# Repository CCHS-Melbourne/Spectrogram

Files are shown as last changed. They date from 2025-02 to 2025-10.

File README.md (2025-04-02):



# Spectrogram

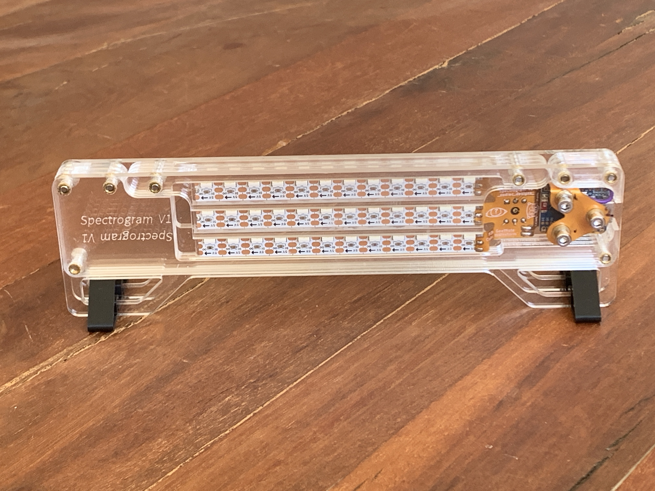
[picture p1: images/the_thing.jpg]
the_thing


It's a 36 LED stack of neopixels joy with an integrated microphone, running MicroPython:

* Audio reactive LEDs
* Acrylic-ready, to show off your creative animations
* Stepped structure to elimate gaps between edge-lit panels
* Touch-enabled to switch between all its range of features

### Building

To build the firmware it helps to use `mpbuild` like so, since this hardware will not work without `ulab`:

```
$ git clone https://github.com/mattytrentini/mpbuild && cd mpbuild
$ git clone https://github.com/v923z/micropython-ulab ulab
$ python3 -mvenv .venv && source .venv/bin/activate && pip install -e .
(.venv)$ mpbuild build ESP32_GENERIC_S3 FLASH_4M USER_C_MODULES=$PWD/ulab/code/micropython.cmake all
```

The resulting object you want to flash with the `esptool.py` command from the previous section is typically named `firmware.bin`.

### Running

```sh
cd software/micropython
./run.sh
```

### Closeup

Uoooohhh

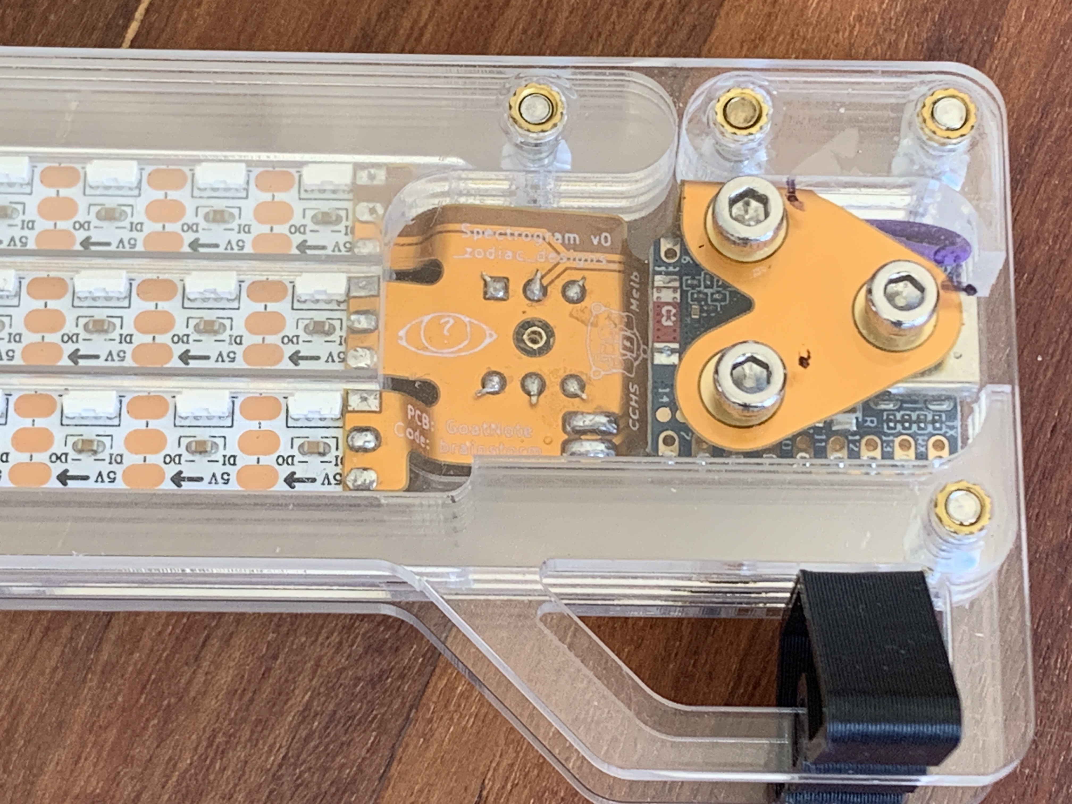
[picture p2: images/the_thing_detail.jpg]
the_thing_detail


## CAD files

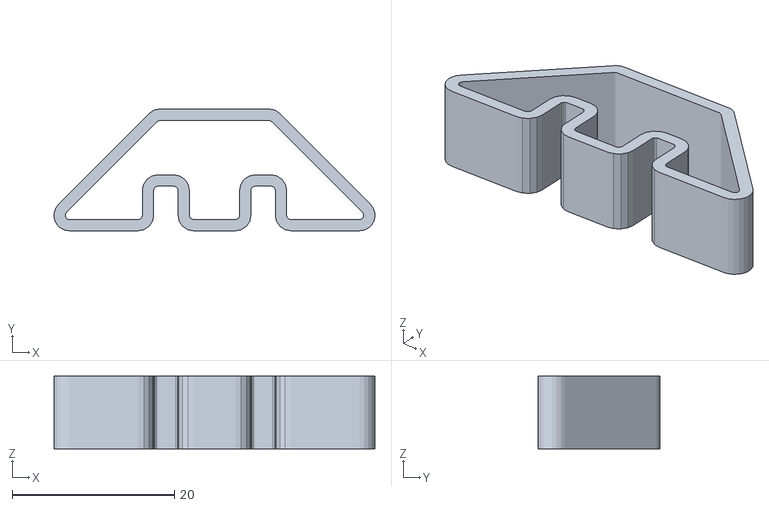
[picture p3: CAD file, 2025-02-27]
hardware/3d_print/foot.stl
39.6 x 15.0 x 9.00

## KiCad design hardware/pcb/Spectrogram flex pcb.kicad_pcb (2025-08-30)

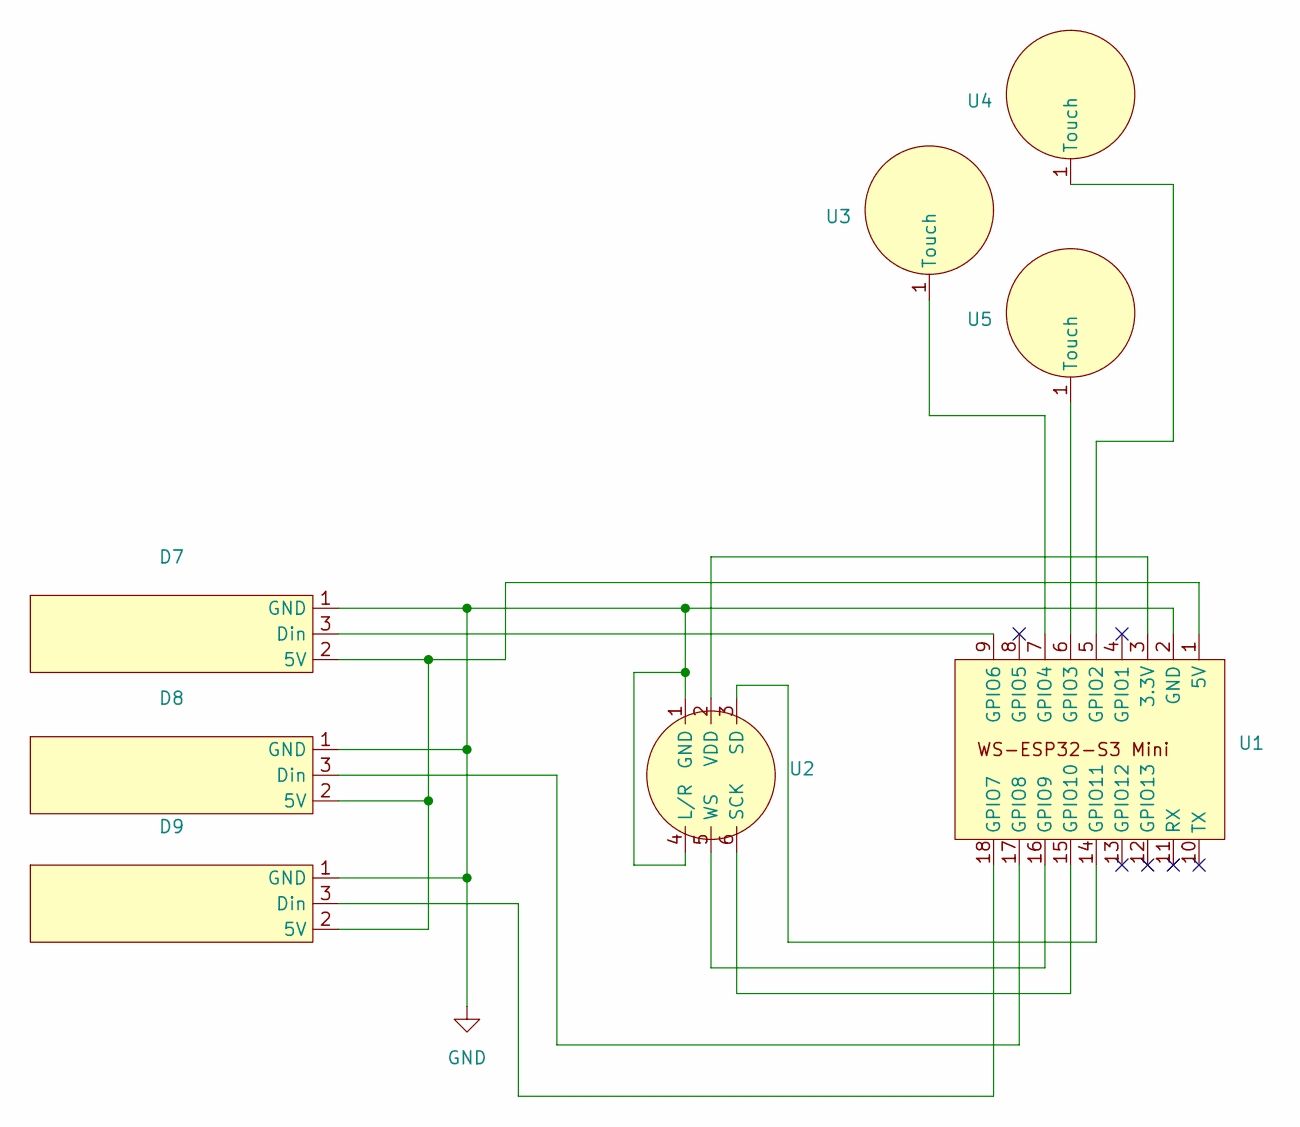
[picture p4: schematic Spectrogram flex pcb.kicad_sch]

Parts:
D7, D8, D9: LED strip ghost
U1: WS-ESP32-S3-Mini
U2: INMP441
U3, U4, U5: Cap touch sensor

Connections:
GND: D7.1 (GND), D8.1 (GND), D9.1 (GND), U1.2 (GND), U2.1 (GND), U2.4 (L/R)
unnamed: D7.2 (5V), D8.2 (5V), D9.2 (5V), U1.1 (5V)
unnamed: D7.3 (Din), U1.9 (GPIO6)
unnamed: D8.3 (Din), U1.17 (GPIO8)
unnamed: D9.3 (Din), U1.18 (GPIO7)
unnamed: U1.3 (3.3V), U2.2 (VDD)
unnamed: U1.5 (GPIO2), U4.1 (Touch)
unnamed: U1.6 (GPIO3), U5.1 (Touch)
unnamed: U1.7 (GPIO4), U3.1 (Touch)
unnamed: U1.16 (GPIO9), U2.5 (WS)
unnamed: U1.15 (GPIO10), U2.6 (SCK)
unnamed: U1.14 (GPIO11), U2.3 (SD)

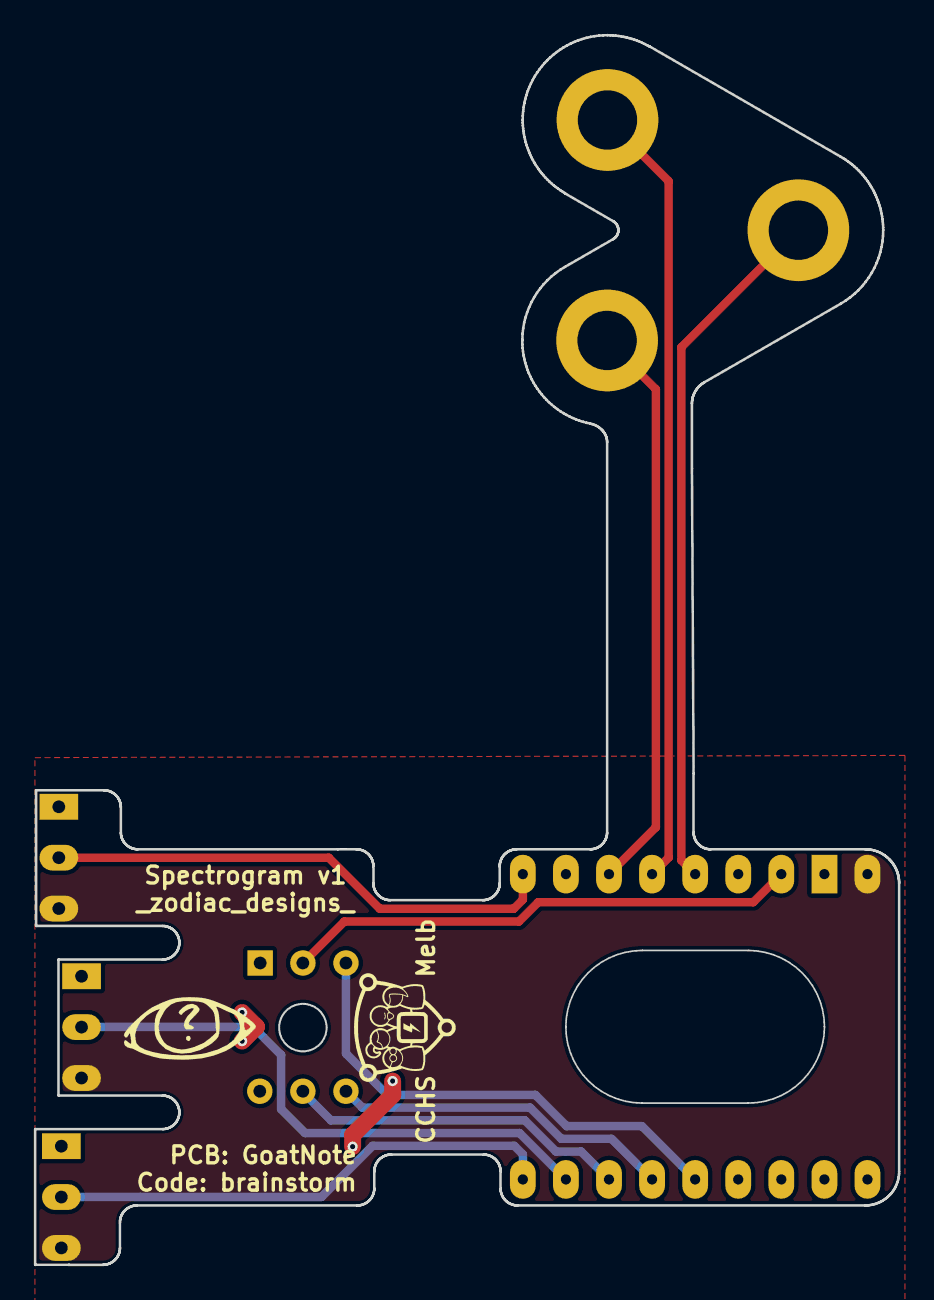
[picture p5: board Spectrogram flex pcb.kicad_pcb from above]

Board: 2 copper layers, 50.9 x 72.5 mm, 8 parts (0 on the bottom side), 12 nets.

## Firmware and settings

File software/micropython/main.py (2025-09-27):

import asyncio
from machine import Pin
from mic import Mic
from debug import set_global_exception
from touch import Touch
from menu import Menu

async def main():
    #set_global_exception()
    touch0 = Touch(Pin(4))
    touch1 = Touch(Pin(3))
    touch2 = Touch(Pin(2))
    microphone = Mic()
    menu = Menu(microphone)
    menu.add_touch(touch0)
    menu.add_touch(touch1)
    menu.add_touch(touch2)

    #print("Starting main gather...")
    await asyncio.gather(touch0.start(), touch1.start(), touch2.start(), menu.start(), microphone.start())
    #await asyncio.gather(microphone.start())
try:
    asyncio.run(main())
finally:
    asyncio.new_event_loop()  # Clear retained state

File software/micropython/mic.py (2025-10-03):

from ulab import utils
import json
import math
import asyncio
from leds import Leds
from ulab import numpy as np
from machine import Pin, I2S
from time import ticks_ms, ticks_diff
from utils.border_calculator import PrecomputedValues
from utils.menu_calculator import PrecomputedMenu

# 512 in the FFT 16000/512 ~ 30Hz update.
# DMA buffer should be at least twice, rounded to power of two.
SAMPLE_RATE = 8000 # Hz
SAMPLE_SIZE = 16
SAMPLE_COUNT = 4096 #8192 #
FREQUENCY_RESOLUTION=SAMPLE_RATE/SAMPLE_COUNT
TUNING_A4_HZ=440.
BINS_PER_OCTAVE=2

# Size of the I2S DMA buffer, the smaller this is then the
# faster each loop iteration can update the LEDs
I2S_SAMPLE_COUNT = 512

I2S_SAMPLE_BYTES = I2S_SAMPLE_COUNT * SAMPLE_SIZE // 8

# Code below assumes the I2S buffer size is an exact multiple of the sample count
assert(SAMPLE_COUNT % I2S_SAMPLE_COUNT == 0)

# Tuning:
#
# - The smaller SAMPLE_COUNT is then the more quickly responsive the LEDs will
#   be. Limit will be a minimum buffer size before the FFT results don't work
#   (TODO: calculate this?)
#
# - The smaller I2S_SAMPLE_COUNT then the higher the update rate for the LEDs so
#   they'll look less jittery. Limit will be a minimum where the CPU can't
#   keep up (because need to perform FFT on full SAMPLE_COUNT for each iteration.)

samples = np.zeros(SAMPLE_COUNT, dtype=np.int16)
sample_bytearray = samples.tobytes()  # bytearray points to the sample samples array
scratchpad = np.zeros(2 * SAMPLE_COUNT) # re-usable RAM for the calculation of the FFT
                                        # avoids memory fragmentation and thus OOM errors

ID = 0
SD = Pin(11)
SCK = Pin(10)
WS = Pin(9)

class Mic():
    def __init__(self):
        self.microphone = I2S(ID, sck=SCK, ws=WS, sd=SD, mode=I2S.RX,
                                bits=SAMPLE_SIZE, format=I2S.MONO, rate=SAMPLE_RATE,
                                ibuf=I2S_SAMPLE_BYTES)

        self.modes=["Intensity","Synesthesia"]
        self.mode=self.modes[0]
#         self.menu_pix=[[],[],[],[],[],[],[],[],[],[],[],[]]#12 values to fill.
        
        self.show_menu_in_mic=False
        self.menu_thing_updating="brightness"
        self.menu_update_required=False
        self.menu_init=True #hopefully just used once a start up.
        
        
        self.max_db_set_point=-40
        self.highest_db_on_record=self.max_db_set_point
        self.lowest_db=-80
        self.db_selection="max_db_set"
        
        self.noise_floor=1000
        
        self.brightnesses=[2,3,4,5,7,10,20,35,50,90,160,255]
        self.brightness_index=4
        self.brightness=self.brightnesses[self.brightness_index] #[0-255]
        
        # Calculate the defined frequencies of the musical notes
#         self.notes=np.arange(1.,85.)
#         self.note_frequencies=TUNING_A4_HZ*(2**((self.notes-49)/12))
        ##print("note frequencies: ", note_frequencies)

        # Event required to change note_per_led number
        self.number_of_octaves=7
        self.notes_per_led_index=4
        self.notes_per_led_options=[1,2,3,4,6,12]
        self.notes_per_led=self.notes_per_led_options[self.notes_per_led_index]
        self.absolute_note_index=0
        
        self.start_range_index=0 #this is a variable that determines where in a precomputed list of ranges of indexes to start displaying the fft results 
        self.full_window_len=12
        self.window_slice_len=12 #this is for clamping the start note when the octave resolution/notes_per_LED is switched 
        self.max_window_overreach=5 #this limit is determined by how many octaves can be shown at once, which is determined by the fft sampling parameters. Currently 7 octaves. 12Leds-7octaves=5 to pad in worst case
        
        self.notes_per_pix_hue=0
        self.octave_shift_hue=42000 #blue, determined by looking at hue learner.
        
        #load the precomupted octave menu and select the dictionary entry that corresponds to the current notes_per_led option
        #create two buffers to avoid async clashes
        self.precomputed_menus=PrecomputedMenu("utils/precomputed_octave_display.json")
        if self.precomputed_menus.load():
            JSON_menu=self.precomputed_menus.get(str(self.notes_per_led))
            self.menu_buffer_a=JSON_menu[self.start_range_index:12]
            self.menu_buffer_b=JSON_menu[self.start_range_index:12]        
        
        #load precomputed values and select the dictionary entry that corresponds to the current notes_per_led option
        #create two buffers to avoid async clashes
        self.precomputed_borders=PrecomputedValues("utils/test_speedup_redo_values.json")
        if self.precomputed_borders.load():
            JSON_boot=self.precomputed_borders.get(str(self.notes_per_led))
            self.fft_ranges_buffer_a=JSON_boot[self.start_range_index:12]
            self.fft_ranges_buffer_b=JSON_boot[self.start_range_index:12]
#             print("FFT_ranges: ", self.fft_ranges_buffer_a)

        #create buffer pointers
        self.active_buffer='a'
        self.menu_to_operate_with=self.menu_buffer_a
        self.fft_ranges_to_operate_with=self.fft_ranges_buffer_a
    
        #create update flags
        self.update_queued=False
        self.next_data_key=None        
        
        self.length_of_leds=13 #actually needs to be number of leds+1, due to how the note border finding/zipping function organizes borders
        self.ring_buffer_hues=np.zeros((3,self.length_of_leds-1))
        self.ring_buffer_intensities=np.zeros((3,self.length_of_leds-1))
        self.buff_index=0
        self.ring_buffer_hues_rgb=[((0,0,0),(0,0,0),(0,0,0),(0,0,0),(0,0,0),(0,0,0),(0,0,0),(0,0,0),(0,0,0),(0,0,0),(0,0,0),(0,0,0)),
                                   ((0,0,0),(0,0,0),(0,0,0),(0,0,0),(0,0,0),(0,0,0),(0,0,0),(0,0,0),(0,0,0),(0,0,0),(0,0,0),(0,0,0)),
                                   ((0,0,0),(0,0,0),(0,0,0),(0,0,0),(0,0,0),(0,0,0),(0,0,0),(0,0,0),(0,0,0),(0,0,0),(0,0,0),(0,0,0))]

        # Figure out what tones correspond to what magnitudes out of the fft, with respect to the mic sampling parameters
        self.tones=FREQUENCY_RESOLUTION*np.arange(SAMPLE_COUNT/2)

        # Set the colours of notes in synaesthesia mode
#         hue_max=65535 #2^16, according to docs in leds.py
#         base_hue=0 #start with red #started learning with/listening to Kate Bush with: 40000
#         hue_diff=5400 #=65535/12=5400, to maximise the step sizes, with some tuning to get good deep blues, ect. #started learning with/listening to Kate Bush with: 5000
#         self.note_hues=np.arange(12.)
#         for i in np.arange(len(self.note_hues)):
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

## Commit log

2024-03-16 Add pcb files, basic micropython led script and i2s examples repo from https://github.com/miketeachman/micropython-i2s-examples
    [Sandwich Panel - Controller v1-2 ESP32.kicad_pcb, Sandwich Panel - Controller v1-2 ESP32.kicad_sch, Sandwich Panel - Controller v1-2 ESP32.sch]
2024-03-16 Further trimming, rename the async tasks according to objectives... correct-ish pin mapping?
2024-03-26 Porting embassy_i2s example and adding in raw bytes serial output, as pointed in https://github.com/esp-rs/esp-println/issues/29#issuecomment-2016969894
    [Sandwich Panel - Controller v1-2 ESP32.kicad_pcb]
2024-03-28 Added async uart, need to orchestrate the buffers since it goes 'task arena is full'
2024-04-20 Migrate from esp32c6 to esp32s3 dev board
2024-05-11 Add probe-rs debugging configuration as outlined in https://docs.esp-rs.org/book/tooling/debugging/probe-rs.html
2024-05-25 Still not working, spectogram is digital on the Rust code... validated that microphone connection is fine with an Arduino WebSockets example...
2024-06-10 Ok, so SmartLed needs to support ::new_async or similar, this will need to go deeper in the rabbit hole...
2024-06-15 Migrate to 0.18.0 esp-hal, changes in embassy packages and uart0 split() is gone. Focusing on SmartLeds + RMT async stuff
2024-06-25 Neat esp32s3 SIMD assembly resource
2024-07-14 Testing ulab's fft spectrogram method... why is everyone else using goertzel algorithm?... something broke, leds are not flashing on boot/main.py now
    [leds.py, main.py]
2024-07-15 Getting I2S init errors:
    #>>> m = mic.Mic()
    #E (37838) i2s_common: i2s_new_channel(867): there should be at least 2 DMA buffers
    #E (37848) i2s_std: i2s_channel_init_std_mode(204): input parameter 'handle' is NULL
    #E (37848) i2s_common: i2s_channel_register_event_callback(316): input parameter 'handle' is NULL
    #E (37858) i2s_common: i2s_channel_enable(1077): input parameter 'handle' is NULL
    I suspect that's ESP-IDF from main (HEAD) since they seem to start moving I2S to a separate compenent/driver that might require DMA arguments.
    So this means to re-run the builder with ESP-IDF 5.0.2 to rebuild micropython image to a known-stable IDF.
    [main.py, mic.py]
2024-07-16 Led lighting show with channel
2024-07-21 hsv2rgb experiments, returning wrong values for now :/
    [leds.py, main.py]
2024-07-21 Testing brightness control, some unexpected blue color glitches, perhaps due to slow modulo/division timing?
    [main.py]
2024-07-24 Open PCB files with KiCad 8.0.0
    [Sandwich Panel - Controller v1-2 ESP32.kicad_sch]
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2024-07-24 Quite a bit of numerical tweaking and optimizations pending here... all leds enabled though
2024-07-26 Profiling... with 36 leds there's an average of nearly 200ms response time, unacceptable
2024-08-03 Correct indentation, change mic pins because the ones of the board lifted... hot glued it now to oblivion, so shouldn't happen again
    [mic.py]
2024-08-04 Shaved off ~100ms, need to put back all the fft_ranges though since I changed SAMPLE_RATE and SAMPLE_COUNT to get closer to chatbot default sampling across the industry/APIs
2024-08-04 Back to all leds, adjusted sample size, we need to discuss led allocation and the need for sum_and_scale
2024-08-10 pushed through led colour map, refactored fft sum scale, binned octaves in fft
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2024-08-11 made ambient noise not scale to max brightness
    The previous intensity scaling code made the lowest ambient noise the brightest colour (bad), then when a loud tone played the noise floor dropped (desirable). Interpolating across a range means that the max value can later be interactively changed, eg, if being used in a loud room
    [mic.py]
2024-08-11 Automated picking of FFT ranges to one octave per led
    in init, calculate the tones resulting of the fft, with respect to the microphone parameters. Calculate the borders of the frequencies with respect to octaves of A. Use the frequencies to check at wh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
2024-08-19 Adding SVG of circuit board refactor
    as above
2024-08-20 Add new prototype outline to a more fitting location
    [refactor-outline.dxf]
2024-08-20 Old zones don't seem to be removable, will edit the text file next, wish me luck
    [Sandwich Panel - Controller v1-2 ESP32.kicad_pcb]
2024-08-20 Successful removal of stray zones (manually)
    [Sandwich Panel - Controller v1-2 ESP32.kicad_pcb]
2024-08-20 Imported SMD microphone, a bunch of footprints are missing (Pancake library)
    [Sandwich Panel - Controller v1-2 ESP32.kicad_pcb, Sandwich Panel - Controller v1-2 ESP32.kicad_sch]
2024-08-20 Change custom testpoints for those present in the default KiCad library
    [Sandwich Panel - Controller v1-2 ESP32.kicad_sch]
2024-08-20 New Edge.Cuts applied
    [Sandwich Panel - Controller v1-2 ESP32.kicad_pcb]
2024-08-28 Add inmp441 mic part for the PCB
    [INMP441.step]
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2024-09-04 Switch to non-blocking I/O, as suggested by Angus
2024-09-07 @projectgus, not sure I'm doing the non_blocking right?:
    ```python
    while True:
    t0 = ticks_us()
    # Use non-blocking instead of streaming mode since we are in a loop!
    num_read = self.microphone.readinto(rawsamples)
    samples = np.frombuffer(rawsamples, dtype=np.int16)
    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
2024-09-08 Thanks @projectgus, very nice speedup!:
    mic sampling: 0 ms
    wled function: 39 ms
    synesthesia : 3 ms
    mic sampling: 1 ms
    wled function: 45 ms
    synesthesia : 2 ms
    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
2024-09-23 Create prototype acrylic edge light freewire 2024_09_19 paring down.svg
2024-09-26 added 'waterfall' or time series mode
    Forgive the -1 and -2 indexing throughout, please.
    Please note that my board now has different pins to yours @brainstorm
2024-10-25 Add ulab+micropython firmware for "Generic" ESP32 and ESP32S3. With latest versions of ulab, micropython, esp-idf and micropython-lib... built with micropython-builder (instead of mpbuild).
    Also the Lolin S3 dev board, which is currently unsupported by micropython upstream (unmerged PR): https://github.com/micropython/micropython/pull/9177
    Firmware images are compiled against ESP-IDF 5.4 series, which require a few tweaks at this point in time: https://github.com/micropython/micropython/issues/15287#issuecomment-2211668377
    The only downsides are some NimBLE security-related data structure and also PPP-related code fixes... neither of which we'll use for now, I reckon.
    Hope those firmware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
2024-10-25 Both asyncio.gather and asyncio.create_task should spawn async tasks and execute them well... instead, I'm finding that when enabling the microphone task, touch does not print(rv) anymore :/
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2024-10-25 Add variant for FLASH_4M (because @GoatNote changed from LOLIN S3 to Waveshare S3 Mini dev board)
2024-10-25 Try another rearrangement when spawning async tasks: first we spawn the 3 touch buttons and then mic... mic task only seems to work when it's the only task spawned (when no touch tasks are spawned)..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
    [main.py]
2024-10-25 Offer minimal guidance to flash this thing on a dev board
2024-10-31 Updating the svgs for the flex PCB outline and acrylic
2024-11-04 touch: Await for the dirty sensor workaround.
    [touch.py]
2024-11-12 Implement ThreadFlag as suggested in https://github.com/CCHS-Melbourne/PancakeLEDs/pull/1#issuecomment-2467146890
    [main.py, mic.py, touch.py]
2024-11-13 Do not await the flag.wait(). Only one iteration of print(id(self), rv) is shown though:
    % mpremote mount .
    Local directory . is mounted at /remote
    Connected to MicroPython at /dev/cu.usbmodem1101
    Use Ctrl-] or Ctrl-x to exit this shell
    >
    MicroPython v1.25.0-preview.22.gfb6c8da on 2024-11-11; Generic ESP32S3 module with ESP32S3
    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
2024-11-16 Updating with my flex PCB design work
    [Spectrogram flex pcb.kicad_pcb, Spectrogram flex pcb.kicad_sch]
2024-11-17 Updating Flex PCB
    [Spectrogram flex pcb.kicad_pcb, Spectrogram flex pcb.kicad_sch]
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2024-11-18 Figuring out why the asyncio tasks block when they shouldn't... now mic intervals are 1 second apart, too much latency
    [main.py, mic.py]
2024-11-18 WIP: untested experiment with making a sliding window for I2S samples
2024-11-19 WIP: Remove some copying and allocations
    By making a 'bytearray' that points into our samples array, and then
    taking a memoryview of this and slicing it, we can copy directly
    from the I2S DMA buffer into our 'samples' array.
2025-02-27 Big cleanup and re-org, let's publish this thing :D
    [INMP441.step, Sandwich Panel - Controller v1-2 ESP32.kicad_pcb, Sandwich Panel - Controller v1-2 ESP32.kicad_sch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]
2025-02-27 Remove prebuilt images for now, moved loose files not related to firmware under utils, pending deletion and/or re-structuring
    [LED_test_flash_all.py, border_calculator.py, leds.py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]
2025-02-27 Add @goatnote 3d printed feet
    [foot.stl]
2025-03-30 Found reason for laggy interface and set 15fps
    The mic did not have a yielding asyncio.await(whatever). Added back in timers and aimed for a 15fps.
2025-03-31 Made menu less overshoot prone, misc crashes, simplified brightness
    Also made the pan mode have the blue colour scheme
    [menu.py, mic.py]
2025-07-26 PCB revision
    [Spectrogram flex pcb.kicad_pcb, Spectrogram flex pcb.kicad_sch]
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2025-09-27 touch ups to work with revised flex pcb and file structure
    [main.py, menu.py, menu_calculator.py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]
2025-10-03 first pass at fixing up synesthesia mode
    [LED_note_hue_picker.py, LED_test_flash_all.py, mic.py]
